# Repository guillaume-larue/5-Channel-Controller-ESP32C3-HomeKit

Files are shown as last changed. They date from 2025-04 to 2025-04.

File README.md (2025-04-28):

# 5-Channel HomeKit Controller (ESP32-C3) 🏠
An open-source DIY controller powered by ESP32-C3 XIAO with HomeKit compatibility, designed for controling  LED strips and DC devices. Perfect for smart home projects! ✨

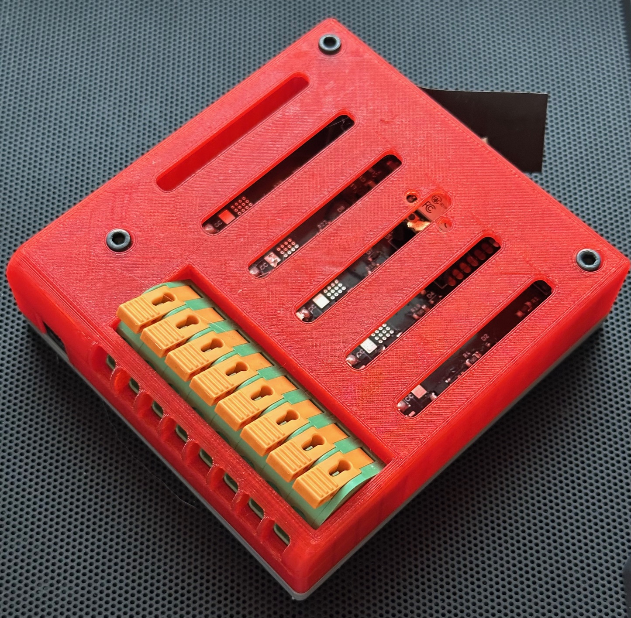
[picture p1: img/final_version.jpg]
Final Result


## Project Structure 📁
This project consists of three main components:
- `hardware/`: Schematics, PCB files, and BOM (Autodesk Fusion exports)
- `firmware/`: Source code for the ESP32-C3
- `enclosure/`: 3D model files for printing the enclosure

## Hardware Design 🛠️
This open-source project centers around a 5-channel controller based on the ESP32-C3 XIAO microcontroller, designed to be compatible with Apple HomeKit through the HomeSpan library. The hardware has been designed using Autodesk Fusion and is capable of controlling various 12/24V DC devices based on PWM signal. The controller can be used to drive a variety of devices, including:
- LED strips (RGB, RGBW, RGBWC)
- Small DC motors
- Similar DC-powered devices
- Etc.

The PCB features robust power handling capabilities, with each channel capable of delivering 6A (20A max total across all channels). At maximum power (~500W at 24V), expect a temperature rise of up to 40°C above ambient.

Key specifications:
- 5 independent control channels
- 12/24V DC input voltage
- HomeKit compatibility via ESP32-C3 XIAO
- Up to 6A per channel (20A total)
- Dual power input options: DC jack or terminal blocks
- Support for both common anode and common cathode configurations

Power can be supplied through either the DC jack or terminal block connections. The board provides 5 independent output channels (CH1-CH5) through terminal blocks.

<table>
  <tr>
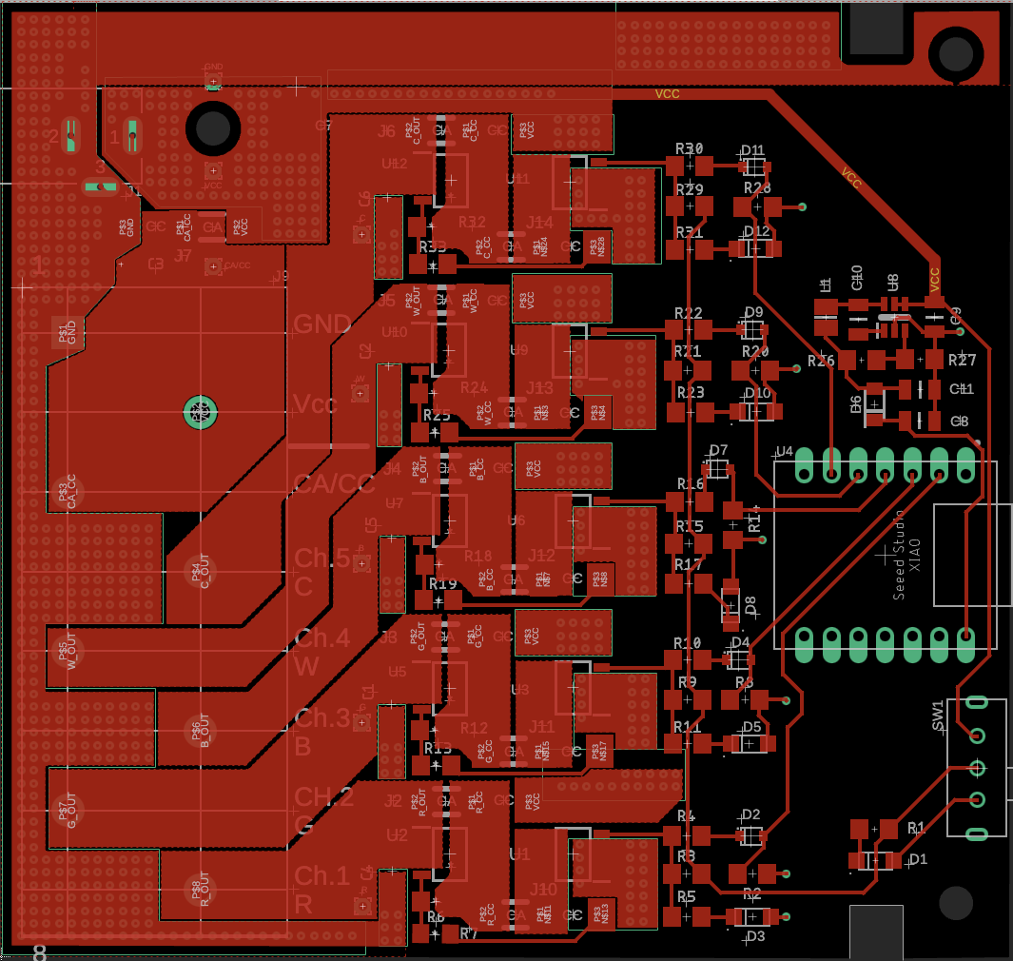
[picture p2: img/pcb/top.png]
    <td></td>
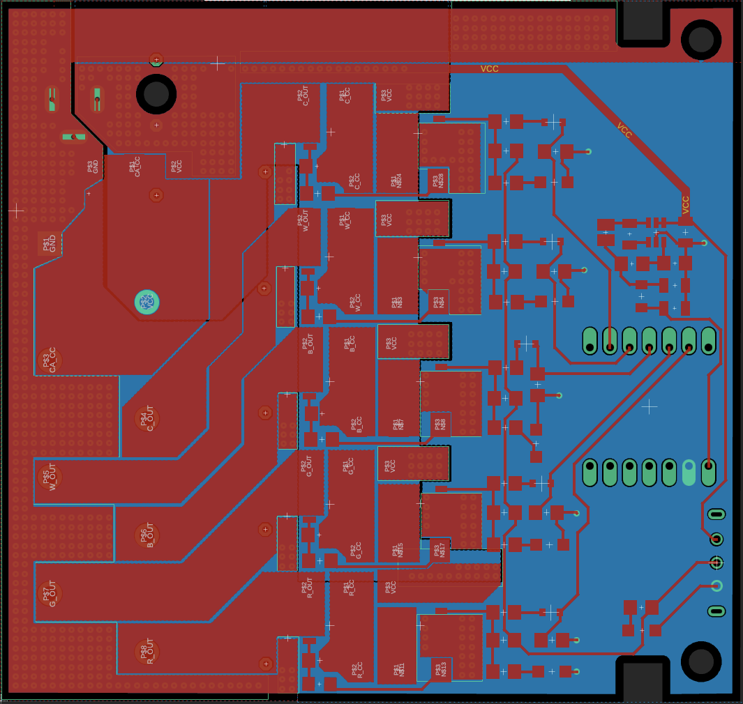
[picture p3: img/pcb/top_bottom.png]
    <td></td>
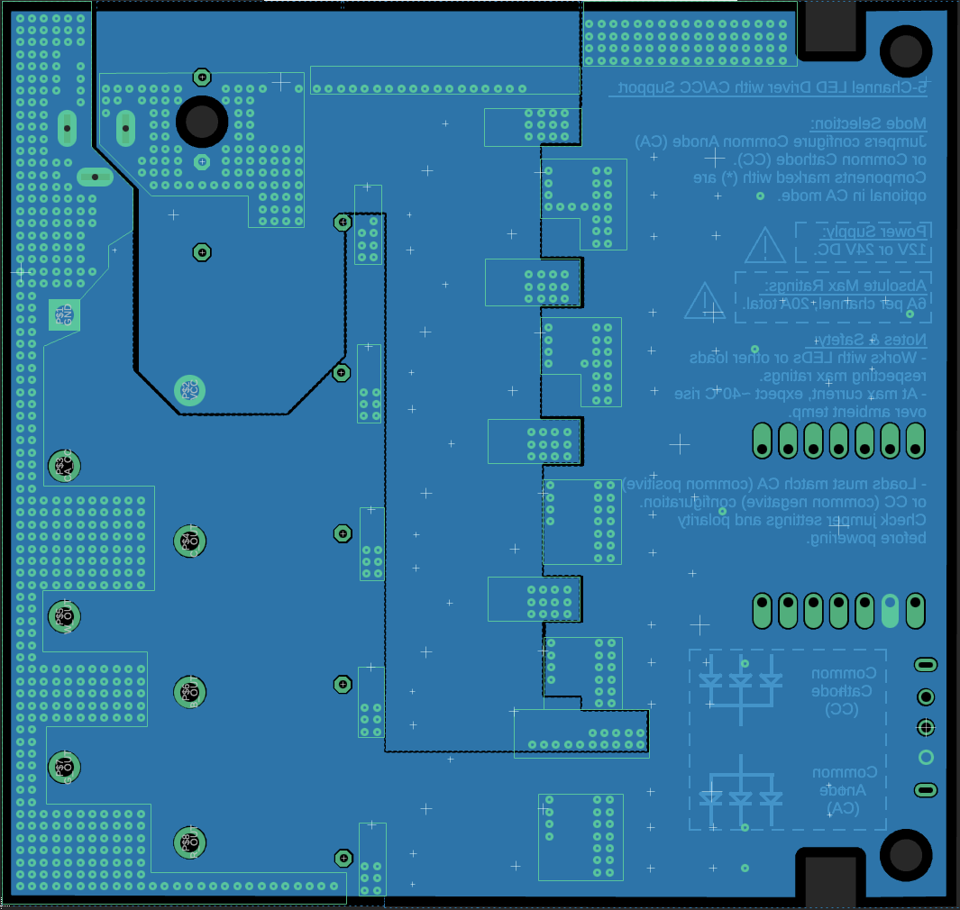
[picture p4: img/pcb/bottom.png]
    <td></td>
  </tr>
  <tr>
    <td align="center">PCB Top</td>
    <td align="center">PCB Top + Bottom</td>
    <td align="center">PCB Bottom</td>
  </tr>
</table>
<table>
  <tr>
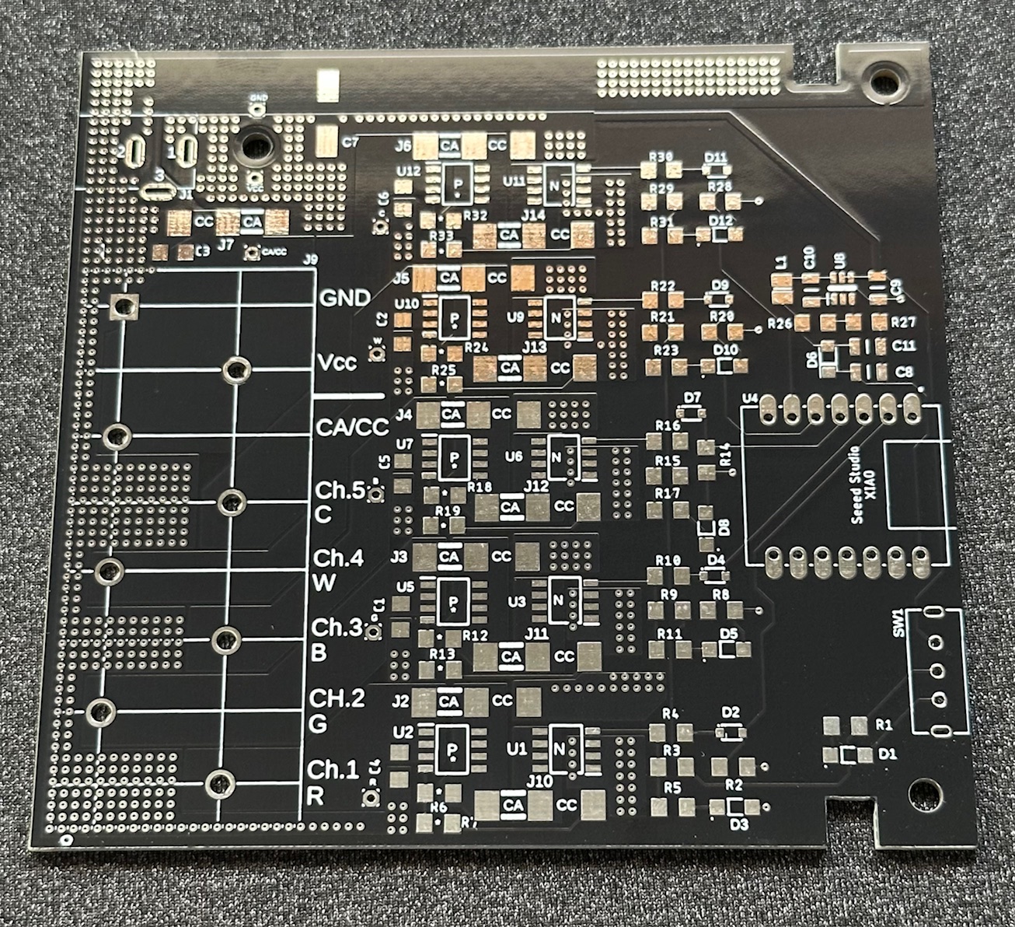
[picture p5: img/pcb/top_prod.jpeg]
    <td></td>
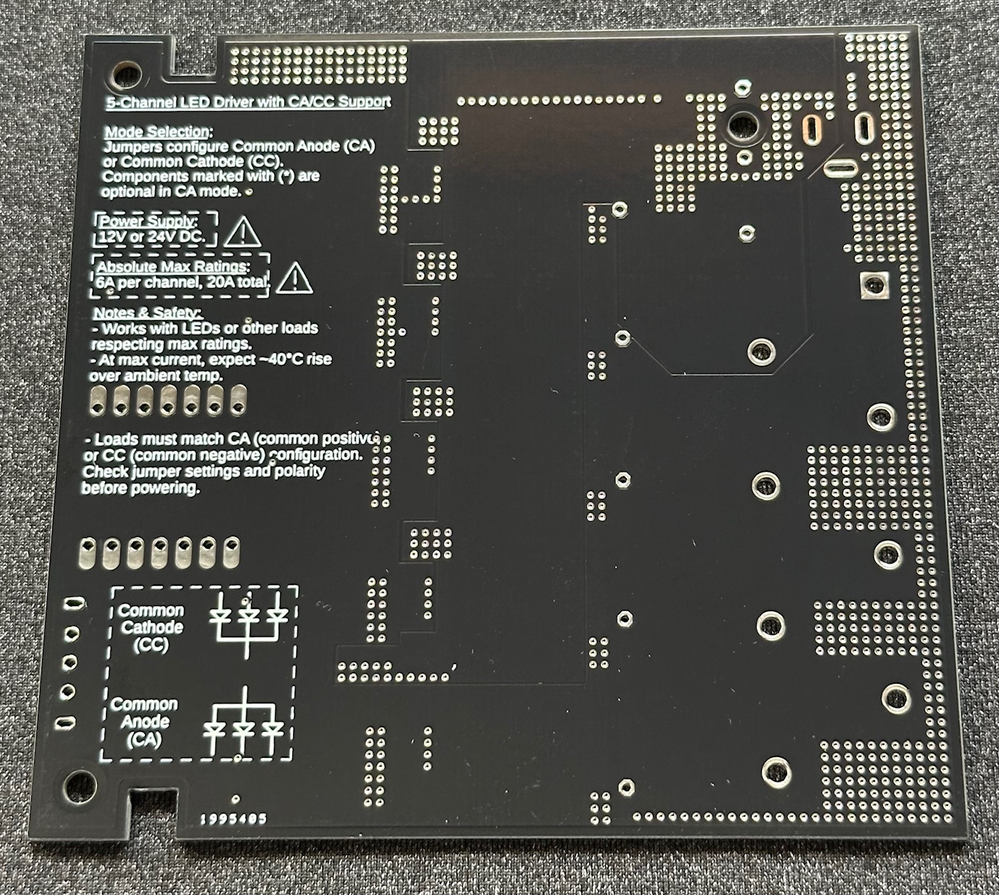
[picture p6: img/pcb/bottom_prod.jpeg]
    <td></td>
  </tr>
  <tr>
    <td align="center">Produced PCB Top</td>
    <td align="center">Produced PCB Bottom</td>
  </tr>
</table>

### Understanding Common Anode vs Common Cathode 💡

The board supports two operating modes, with Common Anode being the recommended choice for most applications:

**Common Anode Mode (Recommended):**
This simpler configuration uses a shared positive (+) connection and N-channel MOSFETs for direct control of each channel. The MOSFETs act as low-side switches, sinking current to the lower rail (ground). Think of it as controlling the negative side while all positives are connected together. This is the default and most common configuration for RGB LED strips and similar devices, requiring fewer components on the PCB.

Technical implementation: The microcontroller drives N-channel MOSFETs that directly control the LED strips channel by connecting them to ground when activated.

**Common Cathode Mode:**
Some specialized LED strips or devices require this mode, where all negatives (-) are connected together. It uses a more complex arrangement with both N-channel and P-channel MOSFETs. The P-MOSFETs act as high-side switches, sourcing current from the upper rail (V+). Components marked with * on the PCB are only needed for this configuration.

Technical implementation: The microcontroller drives N-channel MOSFETs on the lower rail, which in turn control P-channel MOSFETs that source current from the power supply to the LED strips.

Choose Common Anode unless your specific device requires Common Cathode configuration. When in doubt, check your LED strip or device documentation - most standard RGB LED strips use Common Anode.

### Component Options

Several components on the board are optional depending on your needs:
- Common Cathod mode components (marked by *)
- Capacitors C1-C6: Install only if you notice LED flickering or need to filter out the PWM current outpur
- Indicator LEDs (and related resistors): Useful for debugging
- External antenna: XIAO C3 is shipped with an external patch antenna, but the proposed enclosure include a hole to fit better antennas for increased WiFi reception

### Enclosure 🏗️
The provided STL files allow you to 3D print a custom enclosure for the controller. It's designed to be secured with M3 screws and includes a dedicated hole for an optional external antenna.

<table>
  <tr>
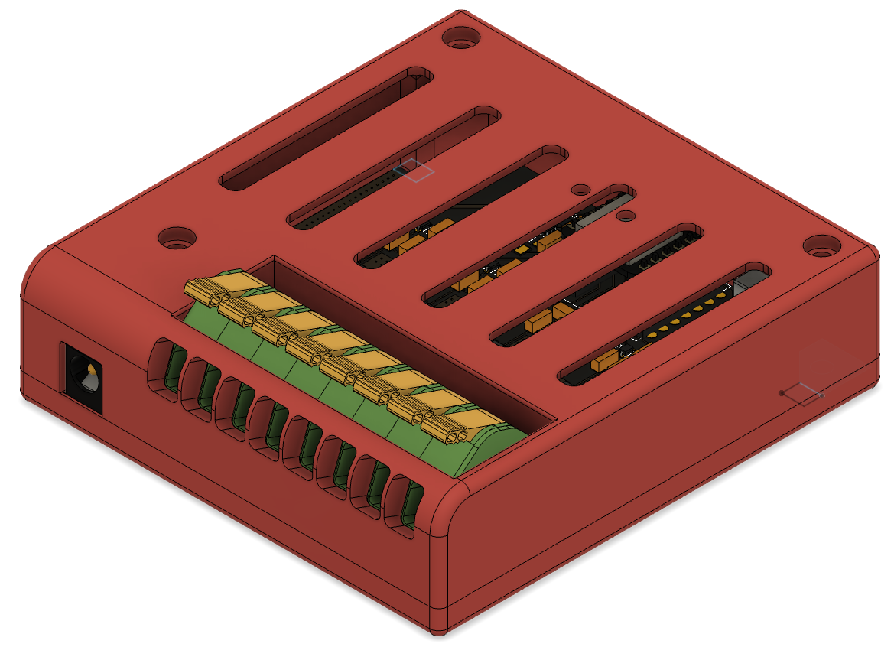
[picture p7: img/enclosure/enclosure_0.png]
    <td></td>
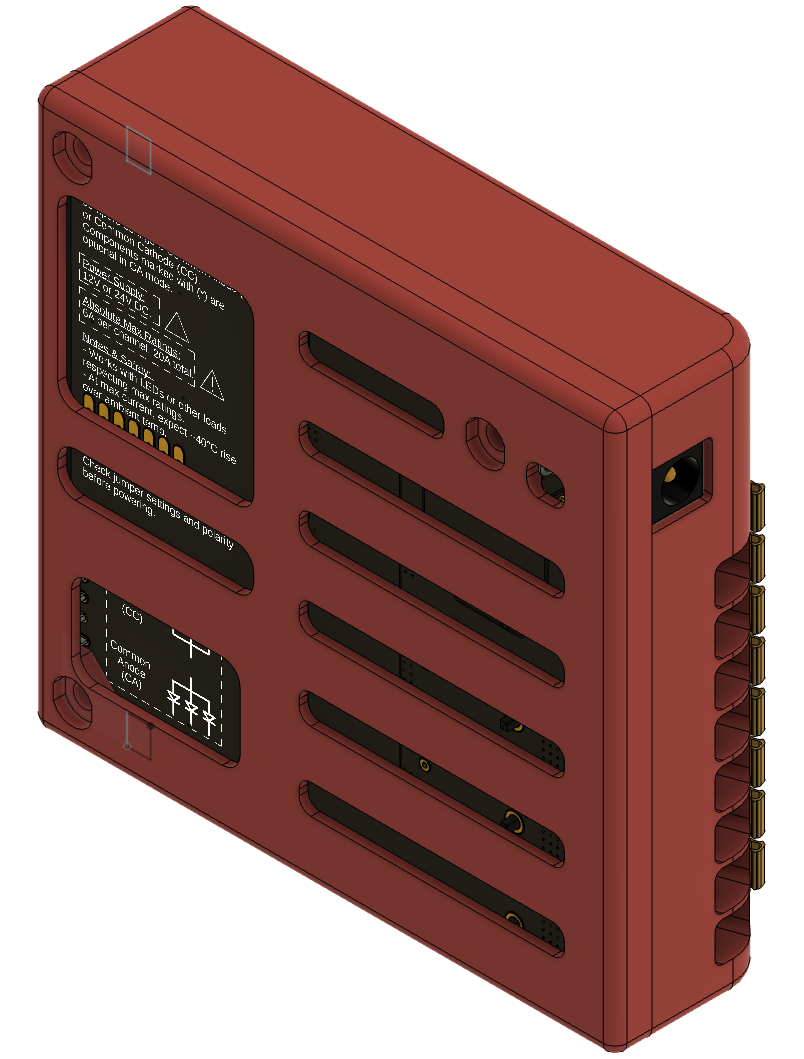
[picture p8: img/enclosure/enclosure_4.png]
    <td></td>
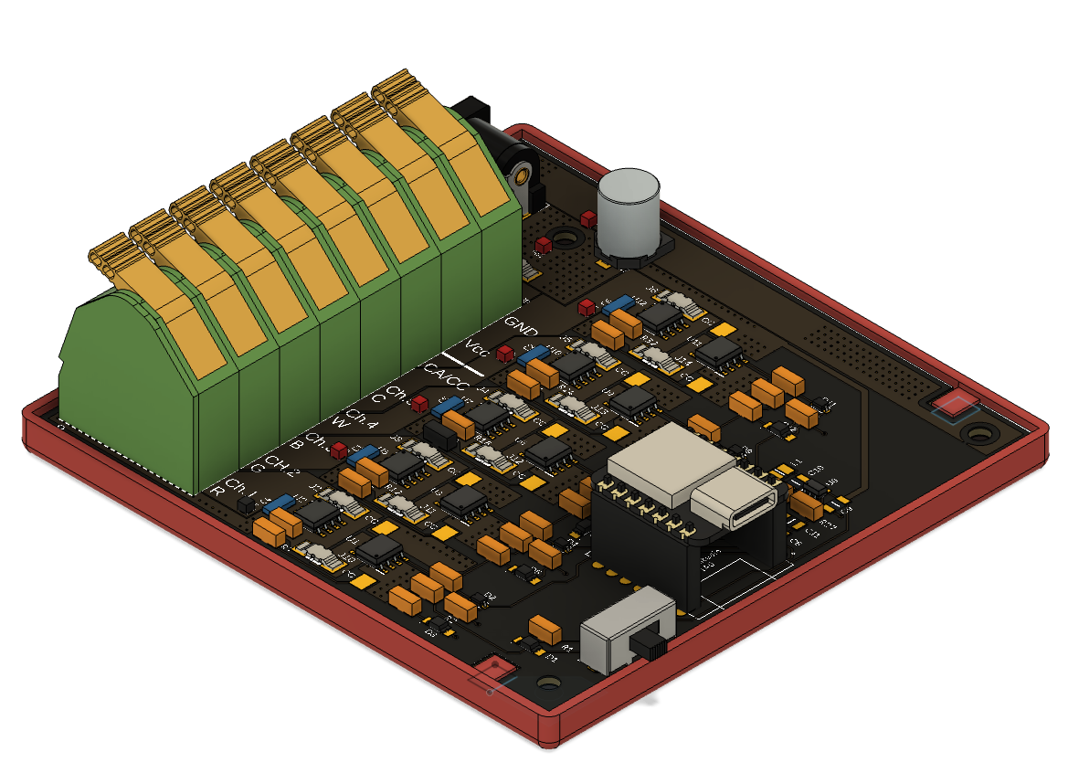
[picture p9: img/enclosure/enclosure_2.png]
    <td></td>
  </tr>
  <tr>
    <td align="center"></td>
    <td align="center">Enclosure</td>
    <td align="center"></td>
  </tr>
</table>

You can view the 3D models directly:
- [Top Shell](enclosure/3D_printing/upper_part.stl)
- [Bottom Shell](enclosure/3D_printing/lower_part.stl)

## Setup Guide 🚀

### Hardware Assembly
Begin by choosing your operating mode (CA/CC) based on your device requirements. Assemble the PCB with the appropriate components.

### Firmware Installation
Connect the device to your computer and follow these steps:

1. Enter bootloader mode: Press BOOT, Press RESET, Release RESET, Release BOOT
2. Configure your (Arduino) IDE with:
- Programmer: esptool
- Board: XIAO_ESP32C3
- Appropriate USB port

Modify the XIAO_ESP32C3.ino file according to your setup (RGB or single LED (provided) - or custom) and upload it to the device.

### HomeKit Configuration
The device creates a "homespan-setup" access point for initial configuration. Connect to it and use the configuration portal to set up your WiFi network and create a device setup code. Once configured, add the device to your Apple Home app using this code.

### Troubleshooting 🔧

**Important Switch Configuration:**
The board features a bypass switch (SW1) that serves as a safety and debug feature. When enabled, it bypasses the microcontroller and sets all outputs to maximum power - useful for testing but prevents normal HomeKit control. Ensure this switch is in the correct position for your intended use:
- Normal operation: Switch OFF (microcontroller controls outputs)
- Bypass mode: Switch ON (all outputs at full power)

**Common Issues:**
If your device isn't responding as expected:
1. Check SW1 switch position (should be OFF for normal operation)
2. Verify the indicator LEDs for channel activity

**Factory Reset:**
If you've previously installed HomeSpan devices, you might need to reset this one before configuration. To do so:
1. Connect to your computer via USB
2. Open Serial Monitor (set line ending to "newline")
3. Send the 'E' command to erase all settings
4. Re-upload the firmware
5. Reconfigure HomeKit settings

For advanced HomeSpan-related troubleshooting options, check the [HomeSpan CLI commands](https://github.com/HomeSpan/HomeSpan/blob/master/docs/CLI.md).

## Safety Notice ⚠️

At maximum rating, this device handles significant power levels. Always:
- Verify power supply ratings
- Check all connections before powering up
- Monitor temperature during initial testing
- Follow proper electrical safety practices

**Disclaimer:** This is an open-source DIY project - the creators and contributors:
- Accept no responsibility for any damage or injury that may result from building or using this device
- Make no guarantees about the device's performance or reliability
- Provide this design "as is" without warranty of any kind

By building and/or using this device, you acknowledge these risks and assume full responsibility for implementing and using the design safely. 

Remember: Incorrect assembly or usage could result in fire, damage to connected devices, or other hazards. When in doubt, seek expert advice!

## Acknowledgments & License 📝

Built with [HomeSpan](https://github.com/HomeSpan/HomeSpan) by Gregg E. Berman.
Both this project and HomeSpan are licensed under the [MIT License](LICENSE).

## Need Help? 🤔
Check the troubleshooting section or raise an issue on GitHub. Happy building! 

Copyright (c) 2023 Guillaume Larue

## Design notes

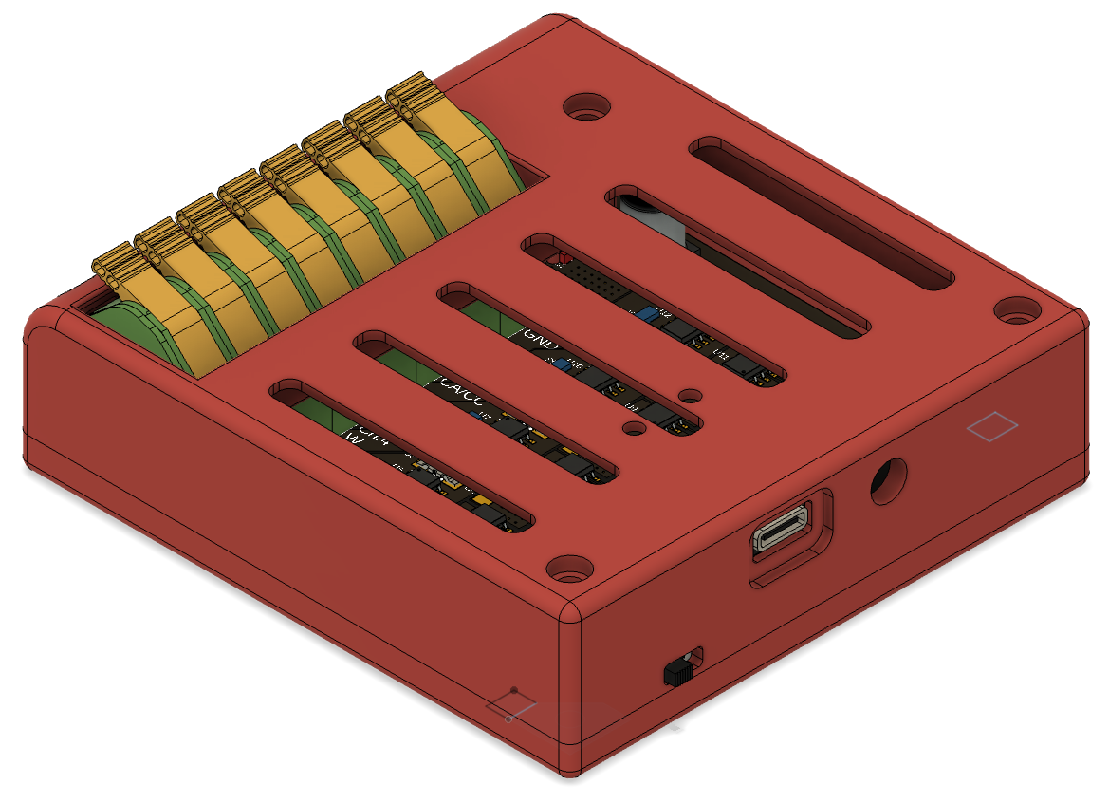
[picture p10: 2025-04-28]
img/enclosure/enclosure_1.png

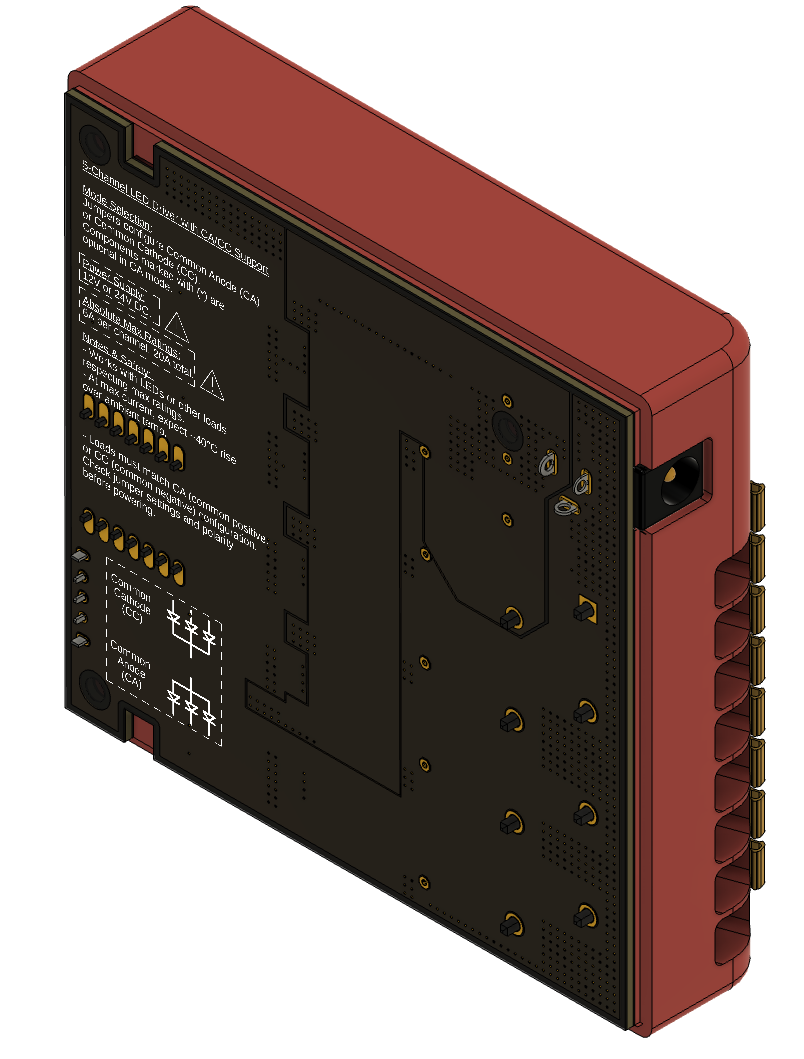
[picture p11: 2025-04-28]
img/enclosure/enclosure_3.png

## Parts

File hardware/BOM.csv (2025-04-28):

DigiKey Reference Number | Qty | Value | Package | Parts | Description
1N5819HW1-7-F | 1 |  | SOD123F | D6 | DIODE SBR 40V 1A SOD123F
35TRV100M8X10.5 | 1 | 100uF | Radial, Can - SMD | C7 | 100 µF 35 V Aluminum Electrolytic Capacitors Radial, Can - SMD 8000 Hrs @ 105°C
36-5102-ND | 11 |  | 5102-2 | J2, J3, J4, J5, J6, J7, J10, J11, J12, J13, J14 | 2 (1 x 2) Position Shunt Connector Non-Insulated 0.114" (2.90mm) Silver
CUS10S30,H3F | 5 |  | SOD-323 | D2, D4, D7, D9, D11 | Diode 30 V 1A Surface Mount USC
TPS560430XFDBVR | 1 |  | SOT-23-6 | U8 | IC REG BUCK PWM 600MA SOT23-6
CL05A104KA5NNNC | 1 | 0.1uF | 1206 | C10 | CAP CER 0.1UF 25V X7R 1206
RC1206FR-0710KL | 15 | 10K | 1206 | R2, R6, R7, R8, R12, R13, R14, R18, R19, R20, R24, R25, R28, R32, R33 | 10 kOhms ±1% 0.25W, 1/4W Chip Resistor 1206 (3216 Metric) Moisture Resistant Thick Film
AOTA-B252010S100MT | 1 | 10uH | 1008 | L1 | FIXED IND 10UH 1.2A 420MOHM SMD
RNCP1206FTD1K00 | 6 | 1K | 1206 | R1, R3, R9, R15, R21, R29 | 1 kOhms ±1% 0.5W, 1/2W Chip Resistor 1206 (3216 Metric) Anti-Sulfur Thin Film
CL31A225KAHNNNE | 1 | 2.2uF | 1206 | C9 | CAP CER 2.2UF 25V X5R 1206
RNCP1206FTD22K1 | 1 | 22.1K | 1206 | R27 | 22.1 kOhms ±1% 0.5W, 1/2W Chip Resistor 1206 (3216 Metric) Anti-Sulfur Thin Film
CL31A226KAHNNNE | 7 | 22uF | 1206 | C1, C2, C3, C4, C5, C6, C11 | 22 µF ±10% 25V Ceramic Capacitor X5R 1206 (3216 Metric)
RMCF1206JT300R | 5 | 300 | 1206 | R5, R11, R17, R23, R31 | RES 300 OHM 5% 1/4W 1206
CL31A476MPHNNNE | 1 | 47uF | 1206 | C8 | CAP CER 47UF 10V X5R 1206
694106301002 | 1 |  |  | J1 | CONN PWR JACK 2.1X5.5MM SOLDER
RMCF1206FT75R0 | 5 | 75 | 1206 | R4, R10, R16, R22, R30 | RES 75 OHM 1% 1/4W 1206
RC1206FR-0788K7L | 1 | 88.7K | 1206 | R26 | RES 88.7K OHM 1% 1/4W 1206
EB171SA-08-M | 1 |  |  | J9 | TERM BLOCK 8POS 30DEG 7.5MM PCB
B1501UYG-20D002513U1930 | 6 |  | 1206 | D1, D3, D5, D8, D10, D12 | Yellow-Green 573nm LED Indication - Discrete 2V 1206 (3216 Metric)
DMG4496SSS-13 | 5 |  | 8-SOIC | U1, U3, U6, U9, U11 | MOSFET N-CH 30V 10A 8SOP
DMP3036SSS-13 | 5 |  | 8-SOIC | U2, U5, U7, U10, U12 | MOSFET P-CH 30V 19.5A 8SO
SLW-129956-4A-RA-N-D | 1 |  |  | SW1 | Slide Switch SPDT Through Hole, Right Angle
XIAOC3ESP32 | 1 |  |  | U4 | Seeed Studio XIAO Series Through-hole Footprint and Symbol

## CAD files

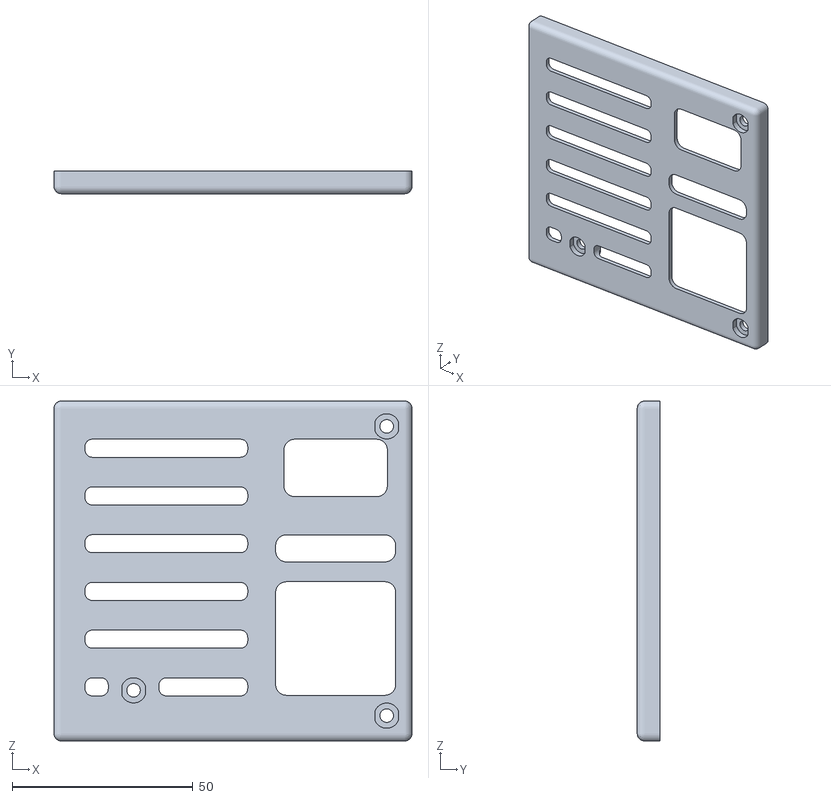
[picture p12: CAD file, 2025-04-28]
enclosure/3D_printing/lower_part.stl
99.0 x 6.23 x 94.0

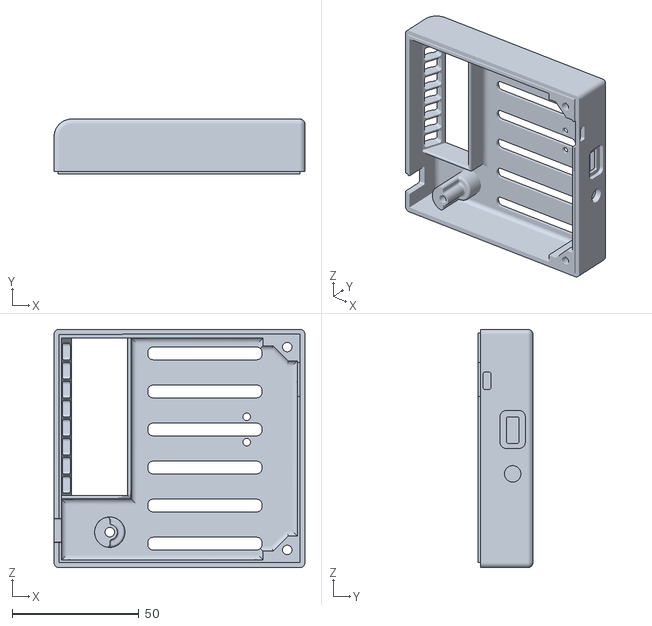
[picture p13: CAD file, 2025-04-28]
enclosure/3D_printing/upper_part.stl
99.0 x 21.7 x 94.0

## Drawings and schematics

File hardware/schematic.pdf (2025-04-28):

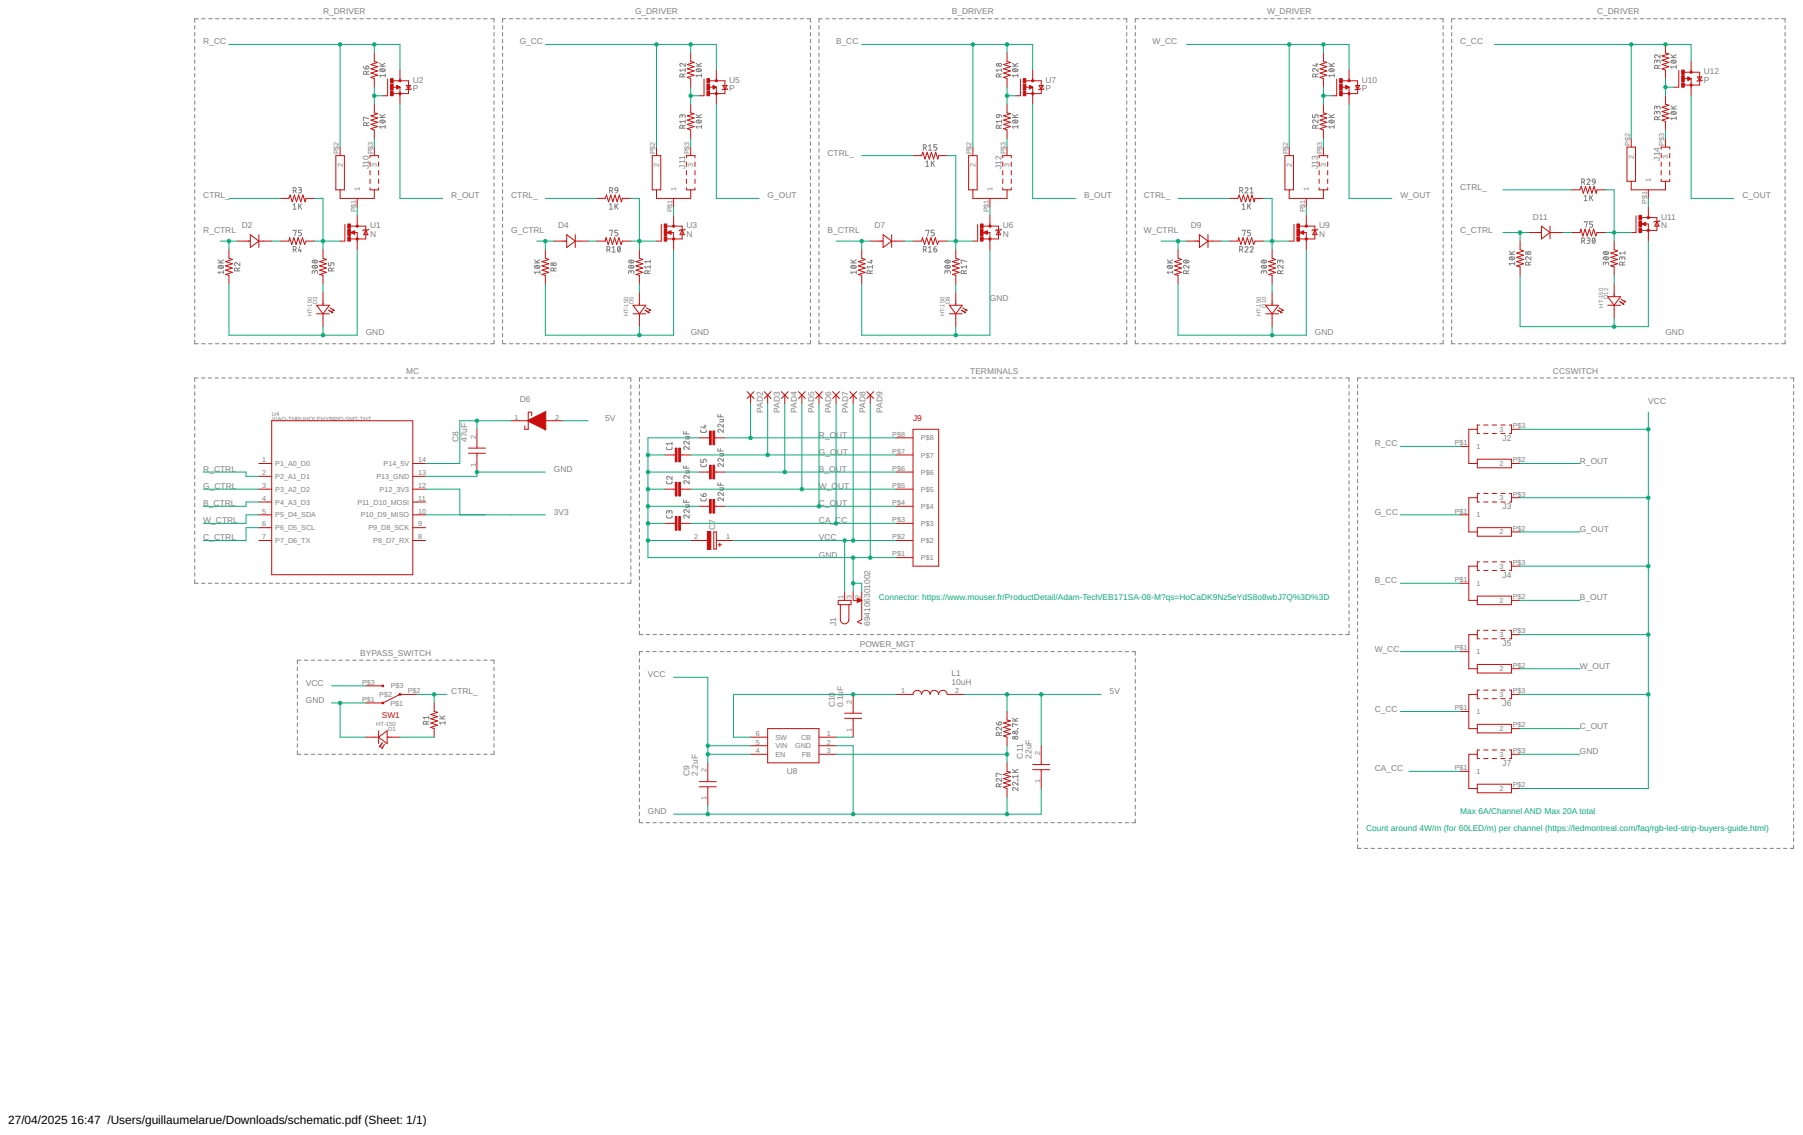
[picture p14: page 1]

XIAO-THRUHOLEHYBRID-SMT-THT

W_OUT | P$1 P$1 P$2 P$2 P$3 P$3 P$4 P$4 P$5 P$5 P$6 P$6 P$7 P$7 P$8 P$8
G_OUT
B_OUT

C_OUT

Connector: https://www.mouser.fr/ProductDetail/Adam-Tech/EB171SA-08-M?qs=HoCaDK9Nz5eYdS8o8wbJ7Q%3D%3D

Max 6A/Channel AND Max 20A total

Count around 4W/m (for 60LED/m) per channel (https://ledmontreal.com/faq/rgb-led-strip-buyers-guide.html)

27/04/2025 16:47 /Users/guillaumelarue/Downloads/schematic.pdf (Sheet: 1/1)

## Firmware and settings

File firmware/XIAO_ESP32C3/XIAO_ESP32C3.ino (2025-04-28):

/*********************************************************************************
* MIT License
* 
* Copyright (c) 2023 Guillaume Larue
* 
* This firmware uses the HomeSpan library (https://github.com/HomeSpan/HomeSpan)
* by Gregg E. Berman, licensed under the MIT License.
*********************************************************************************/

/**
 * XIAO ESP32C3 LED Controller
 * 
 * A HomeKit compatible LED controller supporting both single-channel
 * and RGB configurations, built on the XIAO ESP32C3 platform.
 * 
 * Hardware:
 * - XIAO ESP32C3
 * - Up to 5 channels (PWM outputs)
 * - Common anode or common cathode depending on PCB assembly
 * - 12/24V DC input
 * - Max 6A per channel, 20A total
 * 
 * Features:
 * - HomeKit compatible
 * - Supports single color dimming, RGB control, or any up-to-5 channels topology
 * - Auto AP mode for configuration
 * - Non-volatile state storage
 * 
 */

#include "HomeSpan.h" 
#include "DEV_Identify.h" 
#include "DEV_LED.h" 

// Device Configuration
#define DEVICE_NAME     "XIAO ESP32 C3 LED Controller"
#define MANUFACTURER    "GL"
#define SERIAL_NUMBER   "123-ABC"
#define MODEL          "LED-5CH"
#define VERSION        "0.9"
#define HAP_VERSION    "1.1.0"
#define IDENTIFY_BLINKS 3

// Output Pin Definitions - Map color accordingly
// if additional channels must be used new code must be developped in DEV_LED.h
#define PIN_CH1 D1    // Single LED / Red channel
#define PIN_CH2 D2    // Green channel
#define PIN_CH3 D3    // Blue channel
//#define PIN_CH4 D4  // Additional channel (if needed)
//#define PIN_CH5 D5  // Additional channel (if needed)

/**
 * Initial setup of the device
 */
void setup() {
    // Initialize serial communication
    Serial.begin(115200);
    Serial.println("----------------------------------------");
    Serial.println("Initializing XIAO ESP32C3 LED Controller");
    Serial.println("----------------------------------------");

    // Configure HomeSpan
    homeSpan.enableAutoStartAP();           // Enable auto AP mode for setup

    // Initialize HomeSpan
    homeSpan.begin(Category::Lighting, DEVICE_NAME);

    // Log device configuration
    Serial.println("Device Configuration:");
    Serial.printf("  Name: %s\n", DEVICE_NAME);
    Serial.printf("  Manufacturer: %s\n", MANUFACTURER);
    Serial.printf("  Serial: %s\n", SERIAL_NUMBER);
    Serial.printf("  Model: %s\n", MODEL);
    Serial.printf("  Version: %s\n", VERSION);
    Serial.printf("  HAP Version: %s\n", HAP_VERSION);

    // Create primary accessory
    new SpanAccessory();
    
    // Add mandatory characteristics
    new DEV_Identify(DEVICE_NAME, MANUFACTURER, SERIAL_NUMBER, 
                    MODEL, VERSION, IDENTIFY_BLINKS);
    new Service::HAPProtocolInformation();
    new Characteristic::Version(HAP_VERSION);

    // Add LED service
    #ifdef USE_RGB_LED
        Serial.println("Configuring RGB LED mode");
        new DEV_RgbLED(PIN_CH1, PIN_CH2, PIN_CH3);
    #else
        Serial.println("Configuring Single Channel LED mode");
        new DEV_DimmableLED(PIN_CH1);
    #endif

    Serial.println("----------------------------------------");
    Serial.println("Initialization complete!");
    Serial.println("----------------------------------------");
}

/**
 * Main loop
 */
void loop() {
    homeSpan.poll();
}
